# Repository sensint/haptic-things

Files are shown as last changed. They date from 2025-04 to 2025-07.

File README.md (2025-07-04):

# HAPTICUBES 🧊

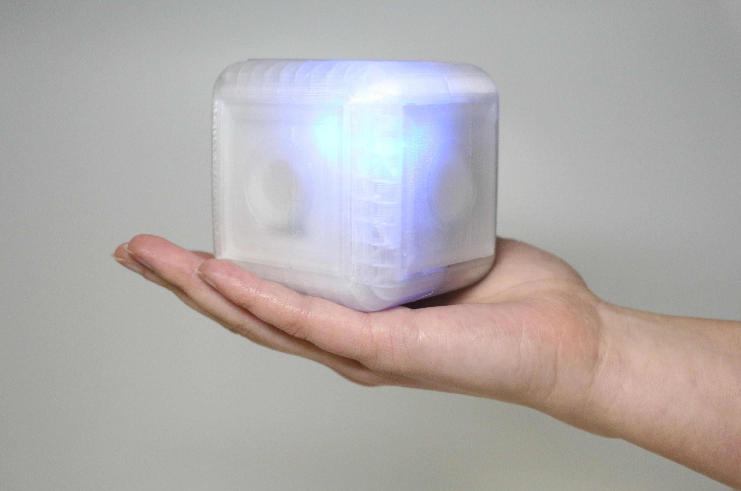
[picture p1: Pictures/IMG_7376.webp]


## Project
A self-contained 3D-printed cube tangible enabling compliance illusion and friction illusion based on motion-coupled vibrotactile rendering with WIFI control.

## Components
1. [Actuator: HAPCOIL-ONE](https://tactilelabs.com/product/hapcoil-one/)
2. [IMU: BNO085](https://www.adafruit.com/product/4754)
3. [RGB LED: APA102](https://www.adafruit.com/product/3341)
4. [Main MCU: Daisy Seed](https://electro-smith.com/products/daisy-seed)
5. [Class D Amplifier: PAM8302](https://www.adafruit.com/product/2130)
6. [Wifi MCU: Wemos D1 Mini](https://www.wemos.cc/en/latest/d1/d1_mini.html)
7. [Force Sensing Resistors: FSR03](https://www.ohmite.com/catalog/fsr-series/FSR03CE)
8. [Battery management: Powerboost 1000](https://www.adafruit.com/product/2465)
9. [Battery: Generic 3.7v Lipo](https://www.adafruit.com/product/1578)

# Wiring 

                           +-----------------------------+
                           |        Daisy Seed MCU       |
                           |                             |
                           |  A0 ──> FSR 1               |
                           |  A1 ──> FSR 2               |
                           |  A2 ──> FSR 3               |
                           |  A3 ──> FSR 4               |
                           |  A4 ──> FSR 5               |
                           |  A5 ──> FSR 6               |
                           |                             |
                           |  SCL1 ─────┐                |
                           |  SDA1 ─────┘──> BNO085 I2C  |
                           |                             |
                           |  TX1 ◄─────────> Weemos D2  |
                           |  RX1 ◄─────────> Weemos D3  |
                           |                             |
                           |  D0 ──> LED DI             |
                           |  D1 ──> LED CLK             |
                           |                             |
                           |  AUDIO OUT 1 ──> Class D Amp|
                           |                             |
                           |  VIN ────┬────────┐         |
                           |  DGND ───┘── AGND │         |
                           +-------------------│---------+
                                               │
                              +----------------▼----------------+
                              |        PowerBoost 1000          |        +---------------------+
                              |   5V OUT ─────┬─────────────────┐ ◄───── |    3.7V LIPO CELL   |
                              |               │                 │        +---------------------+                      
                              |              GND────────────────┘                              
                              +---------------┼-----------------+
                                              ▼
                                  +---------------------+
                                  |     Wemos D1        |
                                  |   3V3 ◄─────────────┘
                                  |   GND ◄─────────────┘
                                  +---------------------+

                                  +---------------------+
                                  |   Class D Amp       |
                                  |   3V3 ◄─────────────┘
                                  |   GND ◄─────────────┘
                                  +---------------------+
                                  
                                  +---------------------+
                                  |     BNO085          |
                                  |   VIN ◄─────────────┘
                                  |   GND ◄─────────────┘
                                  +---------------------+
                                  
                                  +---------------------+
                                  |       LED Strip     |
                                  |   VCC ◄─────────────┘
                                  |   GND ◄─────────────┘
                                  +---------------------+

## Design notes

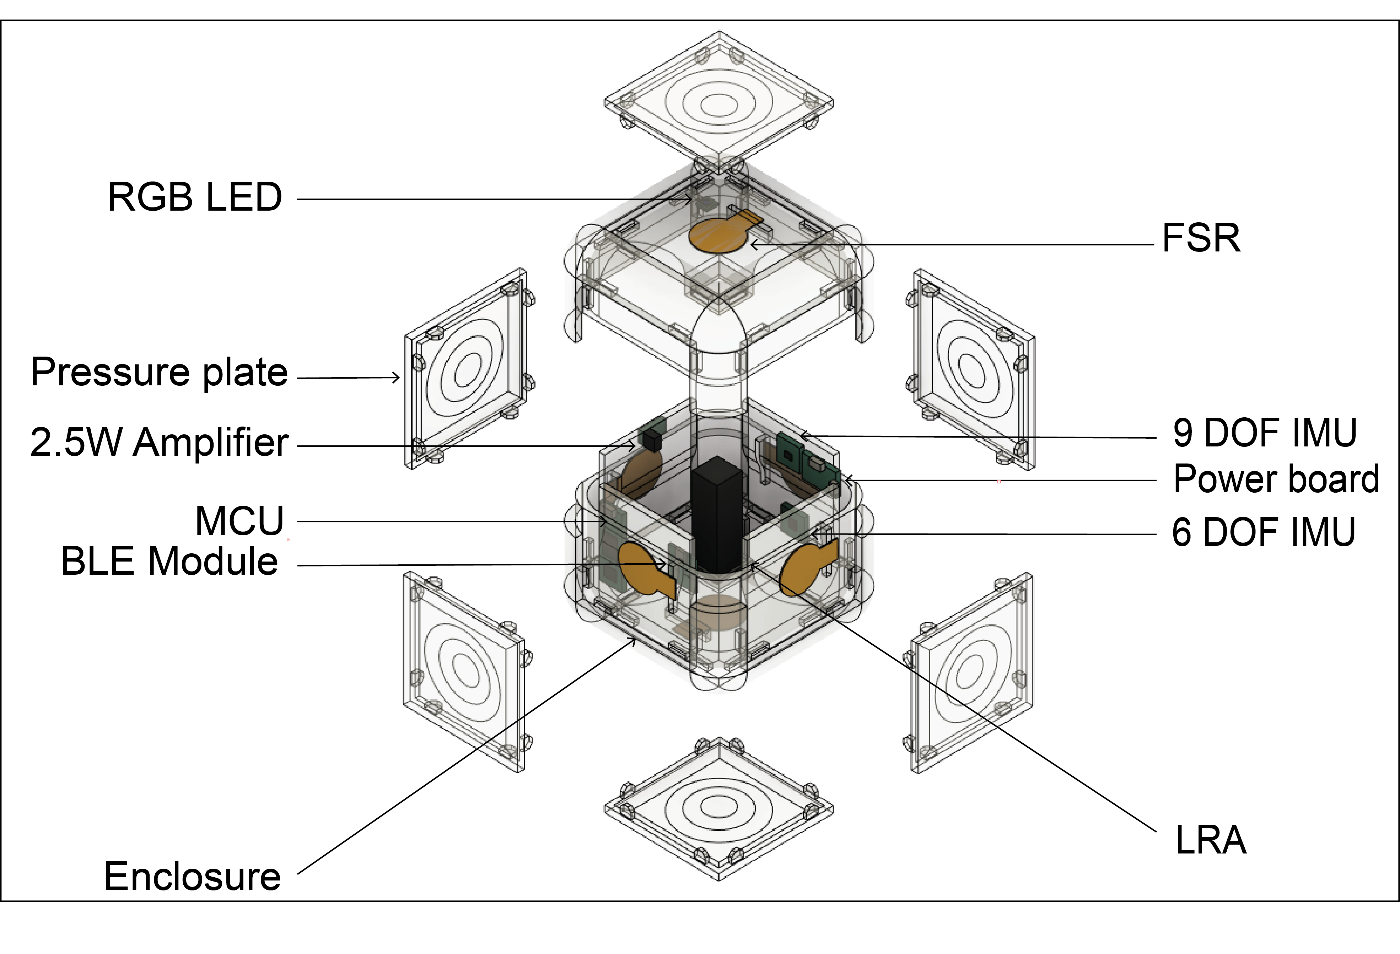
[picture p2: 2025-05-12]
Pictures/CUBE_EXPLODEDview.png

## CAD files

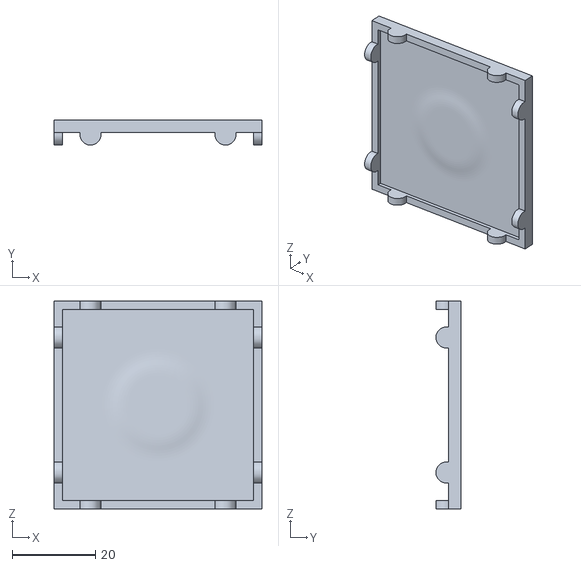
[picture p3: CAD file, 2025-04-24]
STL/FACE_MKIX_V2.stl
49.9 x 6.00 x 49.9

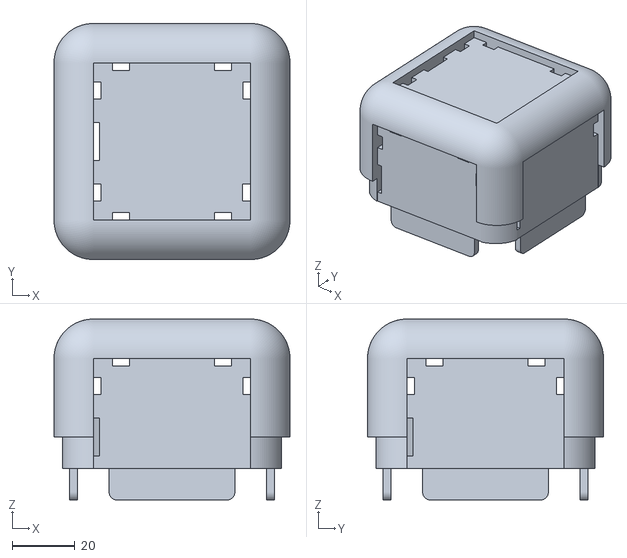
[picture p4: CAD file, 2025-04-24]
STL/CUBE_BOT_MKIX.stl
75.0 x 75.0 x 57.5

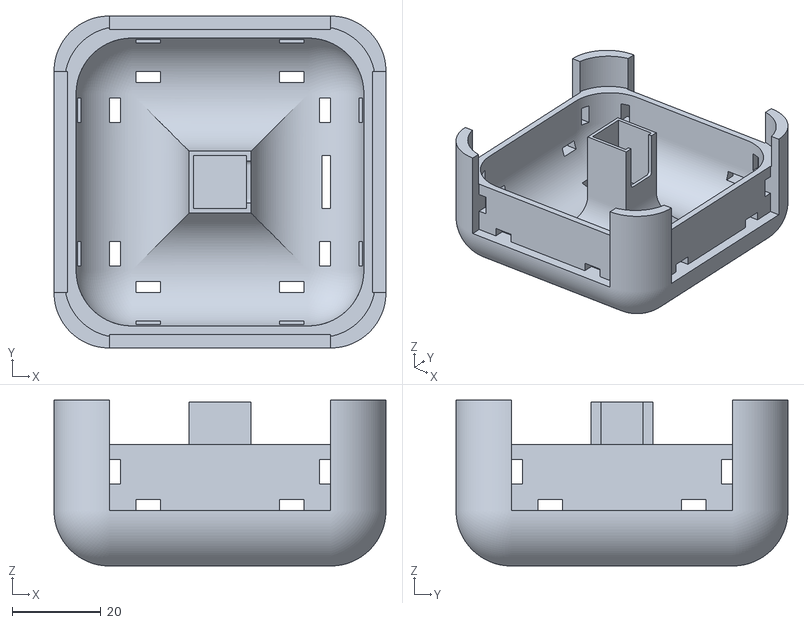
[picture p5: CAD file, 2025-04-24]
STL/CUBE_TOP_MKIX.stl
75.0 x 75.0 x 37.5

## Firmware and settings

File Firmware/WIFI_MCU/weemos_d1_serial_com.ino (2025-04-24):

#include <ESP8266WiFi.h>
#include <ESP8266WebServer.h>
#include <SoftwareSerial.h>

// WiFi credentials
const char* ssid = "your wifi id"; // wifi credentials here (setup a hotspot)
const char* password = "your wifi password";

// Web server on port 80
ESP8266WebServer server(80);

// Software serial for communication with Daisy
SoftwareSerial daisySerial(D2, D3); // RX, TX (D2=GPIO4, D3=GPIO0)

// Current parameter values
int currentMode = 1;
int currentFreq = 150;
float currentAmp = 0.7;
int currentDelta = 20;

void setup() {
  Serial.begin(115200);  // Debug serial
  daisySerial.begin(9600); // Communication with Daisy (use lower baud rate for stability)
  
  // Connect to WiFi
  WiFi.begin(ssid, password);
  Serial.print("Connecting to WiFi");
  while (WiFi.status() != WL_CONNECTED) {
    delay(500);
    Serial.print(".");
  }
  Serial.println();
  Serial.print("Connected! IP address: ");
  Serial.println(WiFi.localIP());
  
  // Define web server routes
  server.on("/", handleRoot);
  server.on("/set", handleSet);
  server.begin();
  Serial.println("HTTP server started");
}

void loop() {
  server.handleClient();
  
  // Process any incoming serial data from Daisy
  if (daisySerial.available()) {
    String data = daisySerial.readStringUntil('\n');
    Serial.println("From Daisy: " + data);
  }
}

// void loop() {
//   daisySerial.println("HELLO FROM D1;");
//   delay(1000);

//   if (daisySerial.available()) {
//     String data = daisySerial.readStringUntil('\n');
//     Serial.println("From Daisy: " + data);
//   }
// }

// Send HTML page
void handleRoot() {
  String html = "<!DOCTYPE html><html><head>";
  html += "<meta name='viewport' content='width=device-width, initial-scale=1'>";
  html += "<style>";
  html += "body { font-family: Arial; margin: 20px; max-width: 500px; }";
  html += ".slider { width: 100%; margin: 10px 0; }";
  html += ".control { margin-bottom: 20px; }";
  html += "button { padding: 10px; margin-right: 5px; cursor: pointer; }";
  html += ".active { background-color: #4CAF50; color: white; }";
  html += "</style>";
  html += "</head><body>";
  html += "<h1>Haptic Controller</h1>";
  
  // Mode buttons
  html += "<div class='control'>";
  html += "<h3>Mode:</h3>";
  html += "<button id='mode0' onclick='setMode(0)'>OFF</button>";
  html += "<button id='mode1' onclick='setMode(1)'>FSR</button>";
  html += "<button id='mode2' onclick='setMode(2)'>Orientation</button>";
  html += "<button id='mode3' onclick='setMode(3)'>Accelerometer</button>";
  html += "</div>";
  
  // Frequency slider
  html += "<div class='control'>";
  html += "<h3>Frequency: <span id='freqValue'>" + String(currentFreq) + "</span> Hz</h3>";
  html += "<input type='range' min='50' max='500' value='" + String(currentFreq) + "' class='slider' id='freqSlider'>";
  html += "</div>";
  
  // Amplitude slider
  html += "<div class='control'>";
  html += "<h3>Amplitude: <span id='ampValue'>" + String(currentAmp) + "</span></h3>";
  html += "<input type='range' min='0' max='0.7' step='0.01' value='" + String(currentAmp) + "' class='slider' id='ampSlider'>";
  html += "</div>";
  
  // Delta threshold slider
  html += "<div class='control'>";
  html += "<h3>Delta Threshold: <span id='deltaValue'>" + String(currentDelta) + "</span></h3>";
  html += "<input type='range' min='5' max='50' value='" + String(currentDelta) + "' class='slider' id='deltaSlider'>";
  html += "</div>";
  
  // Update button
  html += "<button onclick='updateAll()'>Update All</button>";
  
  // JavaScript
  html += "<script>";
  html += "function setMode(mode) {";
  html += "  document.querySelectorAll('button[id^=\"mode\"]').forEach(btn => btn.classList.remove('active'));";
  html += "  document.getElementById('mode'+mode).classList.add('active');";
  html += "  fetch('/set?mode='+mode);";
  html += "}";
  
  html += "document.getElementById('freqSlider').oninput = function() {";
  html += "  document.getElementById('freqValue').textContent = this.value;";
  html += "};";
  
  html += "document.getElementById('ampSlider').oninput = function() {";
  html += "  document.getElementById('ampValue').textContent = this.value;";
  html += "};";
  
  html += "document.getElementById('deltaSlider').oninput = function() {";
  html += "  document.getElementById('deltaValue').textContent = this.value;";
  html += "};";
  
  html += "function updateAll() {";
  html += "  const freq = document.getElementById('freqSlider').value;";
  html += "  const amp = document.getElementById('ampSlider').value;";
  html += "  const delta = document.getElementById('deltaSlider').value;";
  html += "  fetch('/set?freq='+freq+'&amp='+amp+'&delta='+delta);";
  html += "}";
  
  html += "// Initialize active mode button";
  html += "document.getElementById('mode" + String(currentMode) + "').classList.add('active');";
  
  html += "</script>";
  html += "</body></html>";
  
  server.send(200, "text/html", html);
}

// Handle parameter changes
void handleSet() {
  bool changed = false;
  
  // Check if mode was changed
  if (server.hasArg("mode")) {
    currentMode = server.arg("mode").toInt();
    changed = true;
  }
  
  // Check other parameters
  if (server.hasArg("freq")) {
    currentFreq = server.arg("freq").toInt();
    changed = true;
  }
  
  if (server.hasArg("amp")) {
    currentAmp = server.arg("amp").toFloat();
    changed = true;
  }
  
  if (server.hasArg("delta")) {
    currentDelta = server.arg("delta").toInt();
    changed = true;
  }
  
  // If any parameter changed, send update to Daisy
  if (changed) {
    String cmd = "SET," + String(currentMode) + "," + 
                String(currentFreq) + "," + 
                String(currentAmp) + "," + 
                String(currentDelta) + ";";
                
    daisySerial.println(cmd);
    daisySerial.flush();
    delay(50);

    Serial.println("Sent to Daisy: " + cmd);
  }
  
  server.send(200, "text/plain", "OK");
}

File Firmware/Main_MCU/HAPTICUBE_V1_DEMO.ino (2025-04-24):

/////////////////////////////////////////////////////////
// h e l l o    n i c e   t o   s e e   u   t h e r e  //
/////////////////////////////////////////////////////////

// Delta threshold sweetspots :  FSR > ~20/30 | Orientation > ~5/10 | Accelerometer > ~30/50
// Frequency sweetspots = 70 / 100 / 150 / 200 / 300

#include <Wire.h>
#include <Arduino.h>
#include <DaisyDuino.h>
#include <elapsedMillis.h>
#include <Adafruit_BNO08x.h>
#include <APA102.h>
#include <Adafruit_BNO08x.h>

// --- Serial Buffer for RX/TX COM --- //
#define SERIAL_BUFFER_SIZE 128
char serialBuffer[SERIAL_BUFFER_SIZE];
int serialBufferIndex = 0;

// --- FSR --- //
float smoothedPressureA, smoothedPressureB, smoothedPressureC = 0;
float alpha = 0.5;
int offset = 3;
int sensor0, sensor1, sensor2, sensor3, sensor4, sensor5;
float smoothBuffer0, smoothBuffer1, smoothBuffer2, smoothBuffer3, smoothBuffer4, smoothBuffer5, smoothBufferLin0, smoothBufferLin1, smoothBufferLin2, smoothBufferLin3, smoothBufferLin4, smoothBufferLin5, smoothBufferA, smoothBufferB, smoothBufferC;

// --- delta var --- //
long deltaCurrentA = 0.0;
long deltaCurrentB = 0.0;
long deltaCurrentC = 0.0;

long cumulativeDeltaA = 0;
long cumulativeDeltaB = 0;
long cumulativeDeltaC = 0;

double sensor_pressureA = 0.0;
double sensor_pressureB = 0.0;
double sensor_pressureC = 0.0;

double prev_sensor_pressureA = 0.0;
double prev_sensor_pressureB = 0.0;
double prev_sensor_pressureC = 0.0;

double delta_sensor_pressureA = 0.0;
double delta_sensor_pressureB = 0.0;
double delta_sensor_pressureC = 0.0;

double prev_imu_x = 0.0;
double prev_imu_y = 0.0;
double prev_imu_z = 0.0;

double delta_imu_x = 0.0;
double delta_imu_y = 0.0;
double delta_imu_z = 0.0;

// --- IMU --- //
#ifdef FAST_MODE
  // Top frequency is reported to be 1000Hz (but freq is somewhat variable)
  sh2_SensorId_t reportType = SH2_GYRO_INTEGRATED_RV;
  long reportIntervalUs = 2000;
#else
  // Top frequency is about 250Hz but this report is more accurate
  sh2_SensorId_t reportType = SH2_ARVR_STABILIZED_RV;
  long reportIntervalUs = 5000;
#endif

#define BNO08X_RESET -1
Adafruit_BNO08x  bno08x(BNO08X_RESET);
sh2_SensorValue_t sensorValue;

struct euler_t {
  float yaw;
  float pitch;
  float roll;
} ypr;

float imu_x, imu_y, imu_z;

// Variables to track angle for each axis
float prevAngle_x = 0, prevAngle_y = 0, prevAngle_z = 0;
float totalAngle_x = 0, totalAngle_y = 0, totalAngle_z = 0;
bool isFirstReading = true;  // Flag for the first reading

void quaternionToEuler(float qr, float qi, float qj, float qk, euler_t* ypr, bool degrees = false) {

    float sqr = sq(qr);
    float sqi = sq(qi);
    float sqj = sq(qj);
    float sqk = sq(qk);

    ypr->yaw = atan2(2.0 * (qi * qj + qk * qr), (sqi - sqj - sqk + sqr));
    ypr->pitch = asin(-2.0 * (qi * qk - qj * qr) / (sqi + sqj + sqk + sqr));
    ypr->roll = atan2(2.0 * (qj * qk + qi * qr), (-sqi - sqj + sqk + sqr));

    if (degrees) {
      ypr->yaw *= RAD_TO_DEG;
      ypr->pitch *= RAD_TO_DEG;
      ypr->roll *= RAD_TO_DEG;
    }
}

void quaternionToEulerRV(sh2_RotationVectorWAcc_t* rotational_vector, euler_t* ypr, bool degrees = false) {
    quaternionToEuler(rotational_vector->real, rotational_vector->i, rotational_vector->j, rotational_vector->k, ypr, degrees);
}

// ============ Audio/Haptics Flow signal variables ============ //
elapsedMicros pulseTimeUS = 0;

bool isVibrating = false;
bool shouldVibrate = false;

float deltaTresh = 20.0;  // threshohold imu = 100,  fsr = ~10/30 
float ampValue = 0.0;
float newAmpValue = 0.70; // keep < 0.7 to prevent amp distortion
int freqValue = 150; // 70hz resonant freq for hap MKII - i prefer 100 or 150 or 200Hz, oher are too audible at my onion - base freq varifreq is  -/+ 20%
uint32_t signalDuration;

const int sampleRateHz = 100;
unsigned long sampleInterval = 1000 / sampleRateHz;  // Convert Hz to milliseconds
unsigned long lastSampleTime = 0;                    // Time of the last sample
elapsedMillis timer_imu_data = 0;
unsigned long prevTime = 0;
int variFreq = freqValue;

// ================ DaisyVariables ===============
DaisyHardware hw;
Svf filterLow;
Svf filterHigh;
size_t num_channels;
static Oscillator osc;

// ----------- SERIAL READ Variables ----------------- //
String inputString;
int input0 = 0, input1 = 0, input3 = 0;
float input2;

// --------- Print control -------------- //
int printRefreshRate = 20 * 1000; // in microseconds - 20ms / ~50hz -
unsigned long previousPrintMicros = 0;
bool debugPrint = true;

// --- LEDS --- //
const uint8_t dataPin = 0;
const uint8_t clockPin = 1;
const uint16_t ledCount = 1;
float brightness = 0;
rgb_color colors[ledCount];

APA102<dataPin, clockPin> ledStrip;

// --- Mode management --- //
int modeValue = 1; // 0 -> OFF | 1 -> FSR | 2 -> Orientation | 3 -> Accelerometer | [...]

// --- Callback --- //
void MyCallback(float** in, float** out, size_t size) {
  float sig;
  osc.SetAmp(ampValue);
  osc.SetFreq(freqValue);
  osc.SetWaveform(osc.WAVE_SIN);
  for (size_t i = 0; i < size; i++) {
    sig = osc.Process();
    out[0][i] = sig;
    out[1][i] = sig;
  }
}

// --- Setup --- //
void setup() {
  Serial.begin(115200); // debug serial
  Serial1.begin(9600);  // Use Serial1 for hardware UART
  Wire.begin();

  float sample_rate;
  hw = DAISY.init(DAISY_SEED, AUDIO_SR_48K);
  num_channels = hw.num_channels;
  sample_rate = DAISY.get_samplerate();
  osc.Init(sample_rate);
  osc.SetFreq(freqValue);
  osc.SetAmp(0.0);
  osc.SetWaveform(osc.WAVE_SIN);
  DAISY.begin(MyCallback);
  prevTime = millis();  // Initialize time
  delay(1000);

  Serial.println("Bonjour, Hola, Hello :-)");
  Serial.println("Adafruit BNO08x test!");
  // Try to initialize!
  if (!bno08x.begin_I2C()) {
    Serial.println("Failed to find BNO08x chip");
    while (1) { delay(10); }
  }
  Serial.println("BNO08x Found!");
  setReports(reportType, reportIntervalUs);

  delay(1000);
  //setReports();
}

// --- Loop --- //
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

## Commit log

2024-12-17 fixed 400hz
2024-12-18 Adding imu code
2025-04-24 add stl files
    [CUBE_BOT_MKIX.stl, CUBE_TOP_MKIX.stl, FACE_MKIX_V2.stl]
